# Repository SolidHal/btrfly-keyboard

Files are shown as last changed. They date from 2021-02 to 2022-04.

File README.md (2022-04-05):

# btrfly

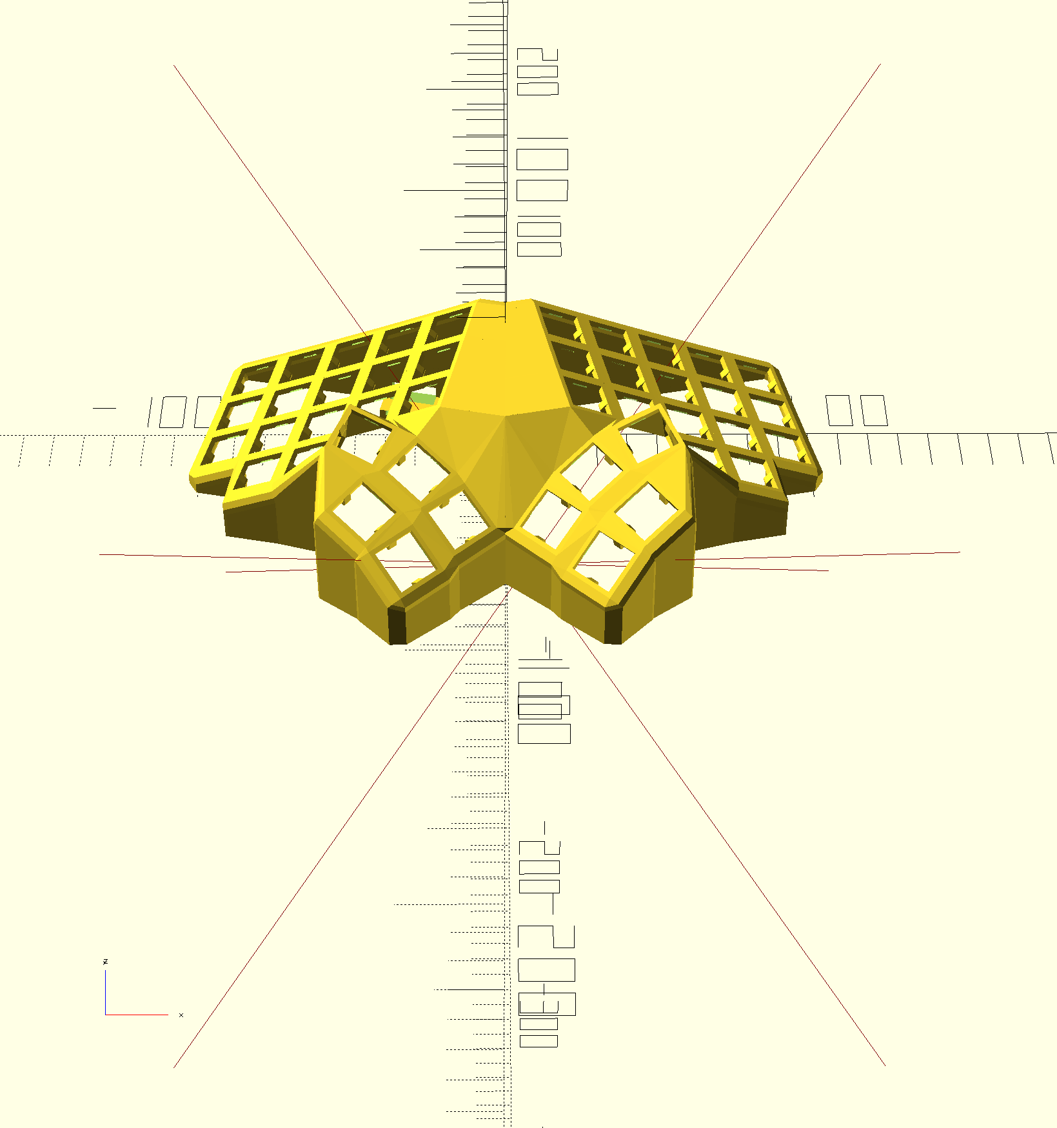
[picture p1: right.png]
render


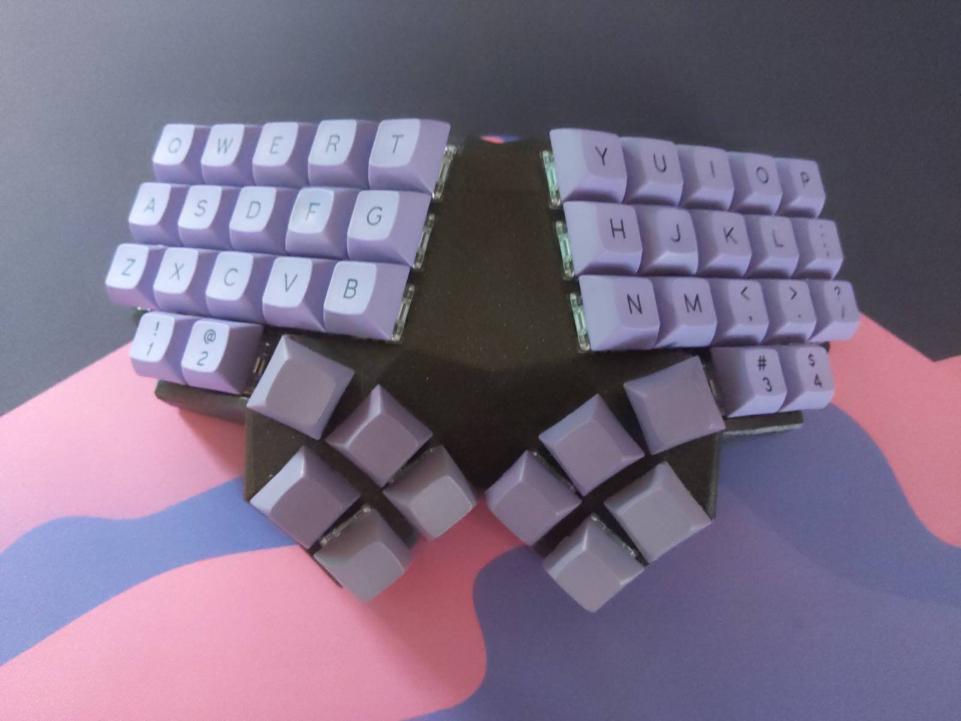
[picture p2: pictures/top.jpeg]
assembled


more pictures in `pictures`

This is a fork of the [Dactyl-ManuForm](https://github.com/tshort/dactyl-keyboard). The Dactyl-Manuform is a fork of the [Dactyl](https://github.com/adereth/dactyl-keyboard) with the thumb cluster from [ManuForm](https://github.com/jeffgran/ManuForm).

## Wiring

No "pretty" diagram for now, but there is an ugly hand drawn schematic. see `wiring.jpeg`

The schematic is from the perspective of the underside of the keyboard. 

Most of the "usual" dactyl wiring rules apply here.

ProMicro Pinout
```
C = colomn
R = Row

C0 = D3  USB   RAW
C1 = D2        GND
     GND       RST
     GND       VCC
C2 = D1        F4
C3 = D0        F5
C4 = D4        F6
C5 = C6        F7 = R0
C6 = D7        B1 = R1
C7 = E6        B3 = R2
C8 = B4        B2 = R3
C9 = B5        B6 = R4
```

## Build QMK
copy qmk/microdactyl to a new qmk checkout, under the keybaords/handwired directory
```
cp -a qmk/btrfly $QMK_DIR/keyboards/handwired/
```
then flash by running the following from your qmk checkout
```
make handwired/btrfly:default:flash
```

## Features

- dactyl-manuform-mini thumb cluster
- flat, tented qwerty keys
- 4 extra mappable keys

## Generate OpenSCAD and STL models

* Run `lein generate` or `lein auto generate`
* This will regenerate the `things/*.scad` files
* Use OpenSCAD to open a `.scad` file.
* Make changes to design, repeat `load-file`, OpenSCAD will watch for changes and rerender.
* When done, use OpenSCAD to export STL files

* NOTE: in the code, the btrfly keyboard is sometimes called "squish"

## In the wild
https://old.reddit.com/r/ErgoMechKeyboards/comments/nozw1c/btrfly_with_kissboard_configuration_my_first_diy/

## License

Copyright © 2021 Hal Emmerich
Copyright © 2015-2018 Matthew Adereth, Tom Short and Leo Lou

The source code for generating the models is distributed under the [GNU AFFERO GENERAL PUBLIC LICENSE Version 3](LICENSE).

The generated models are distributed under the [Creative Commons Attribution-ShareAlike 4.0 International (CC BY-SA 4.0)](LICENSE-models).

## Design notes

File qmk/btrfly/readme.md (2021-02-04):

# Microdactyl

to flash this keymap, grab a copy of qmk, copy this "microdactyl" directory into qmk/keyboards/handwired and from the qmk root run:
```
make handwired/microdactyl/4x6:default:flash
```

you can also get a .json file to upload to the qmk configurator by running:
```
./bin/qmk c2json -km DEFAULT -kb handwired/microdactyl/4x6 'keyboards/handwired/microdactyl/4x6/keymaps/default/keymap.c' > microdactyl.json 
```

to get the configurator to recognize the file you might have to change the keyboard name to `handwired/dactyl-manuform/4x6`

Dactyl Manuform (4x5, 5x6, 5x7, 6x6)
======
the [Dactyl-Manuform](https://github.com/tshort/dactyl-keyboard) is a split curved keyboard based on the design of [adereth dactyl](https://github.com/adereth/dactyl-keyboard) and thumb cluster design of the [manuform](https://geekhack.org/index.php?topic=46015.0) keyboard, the hardware is similar to the let's split keyboard. all information needed for making one is in the first link.
Imgur

## First Time Setup

Download or clone the `qmk_firmware` repo and navigate to its top level directory. Once your build environment is setup, you'll be able to generate the default .hex using:

Depending on your Layout chose one of the follwing commands:

```
$ make handwired/dactyl_manuform/YOUR_LAYOUT:YOUR_KEYMAP_NAME
```

example:
```
$ make handwired/dactyl_manuform/4x5:default
```

If everything worked correctly you will see a file:

```
dactyl_manuform_YOUR_LAYOUT_YOUR_KEYMAP_NAME.hex
```

For more information on customizing keymaps, take a look at the primary documentation for [Customizing Your Keymap](/docs/faq_keymap.md) in the main readme.md.

## Keymaps

### [Keymaps 4x5](/keyboards/handwired/dactyl_manuform/4x5/keymaps/)

#### Default
Simple QWERTY layout with 3 Layers.
#### Dvorak

### [Keymaps 5x6](/keyboards/handwired/dactyl_manuform/5x6/keymaps/)

#### Default
Just a copy of the Impstyle keymap. Feel free to adjust it.

#### Impstyle
A simple QWERTY keymap with 3 Layers. Both sides are connected via serial and the Left ist the master.

### [Keymaps 5x7 aka almost Ergodox](/keyboards/handwired/dactyl_manuform/5x7/keymaps/)
#### Default
Keymap of Loligagger from geekhack.

### [Keymaps 6x6](/keyboards/handwired/dactyl_manuform/6x6/keymaps/)

#### Default
Simple QWERTY layout with 3 Layers.

## Required Hardware

Apart from diodes and key switches for the keyboard matrix in each half, you
will need:

* 2 Arduino Pro Micros. You can find these on AliExpress for ≈3.50USD each.
* 2 TRRS sockets and 1 TRRS cable, or 2 TRS sockets and 1 TRS cable

Alternatively, you can use any sort of cable and socket that has at least 3
wires. If you want to use I2C to communicate between halves, you will need a
cable with at least 4 wires and 2x 4.7kΩ pull-up resistors

## Optional Hardware
A speaker can be hooked-up to either side to the `5` (`C6`) pin and `GND`, and turned on via `AUDIO_ENABLE`.

## Wiring

The 3 wires of the TRS/TRRS cable need to connect GND, VCC, and digital pin 3 (i.e.
PD0 on the ATmega32u4) between the two Pro Micros.

Next, wire your key matrix to any of the remaining 17 IO pins of the pro micro
and modify the `matrix.c` accordingly.

The wiring for serial:

serial wiring

The wiring for i2c:

i2c wiring

The pull-up resistors may be placed on either half. It is also possible
to use 4 resistors and have the pull-ups in both halves, but this is
unnecessary in simple use cases.

You can change your configuration between serial and i2c by modifying your `config.h` file.

## Notes on Software Configuration

the keymaps in here are for the 4x5 layout of the keyboard only.

## Flashing

To flash your firmware take a look at: [Flashing Instructions and Bootloader Information](https://docs.qmk.fm/#/flashing)

## Choosing which board to plug the USB cable into (choosing Master)

Because the two boards are identical, the firmware has logic to differentiate the left and right board.

It uses two strategies to figure things out: looking at the EEPROM (memory on the chip) or looking if the current board has the usb cable.

The EEPROM approach requires additional setup (flashing the eeprom) but allows you to swap the usb cable to either side.

The USB cable approach is easier to setup and if you just want the usb cable on the left board, you do not need to do anything extra.

### Setting the left hand as master

If you always plug the usb cable into the left board, nothing extra is needed as this is the default. Comment out `EE_HANDS` and comment out `I2C_MASTER_RIGHT` or `MASTER_RIGHT` if for some reason it was set.

### Setting the right hand as master

If you always plug the usb cable into the right board, add an extra flag to your `config.h`
```
 #define MASTER_RIGHT
```

### Setting EE_hands to use either hands as master

If you define `EE_HANDS` in your `config.h`, you will need to set the
EEPROM for the left and right halves.

The EEPROM is used to store whether the
half is left handed or right handed. This makes it so that the same firmware
file will run on both hands instead of having to flash left and right handed
versions of the firmware to each half. To flash the EEPROM file for the left
half run:
```
make handwired/dactyl_promicro:default:dfu-split-left
make handwired/dactyl_promicro:default:dfu-split-right
```

After you have flashed the EEPROM, you then need to set `EE_HANDS` in your config.h, rebuild the hex files and reflash.

Note that you need to program both halves, but you have the option of using
different keymaps for each half. You could program the left half with a QWERTY
layout and the right half with a Colemak layout using bootmagic's default layout option.
Then if you connect the left half to a computer by USB the keyboard will use QWERTY and Colemak when the
right half is connected.

Notes on Using Pro Micro 3.3V
-----------------------------

Do update the `F_CPU` parameter in `rules.mk` to `8000000` which reflects
the frequency on the 3.3V board.

Also, if the slave board is producing weird characters in certain columns,
update the following line in `matrix.c` to the following:

```
// wait_us(30);  // without this wait read unstable value.
wait_us(300);  // without this wait read unstable value.
```

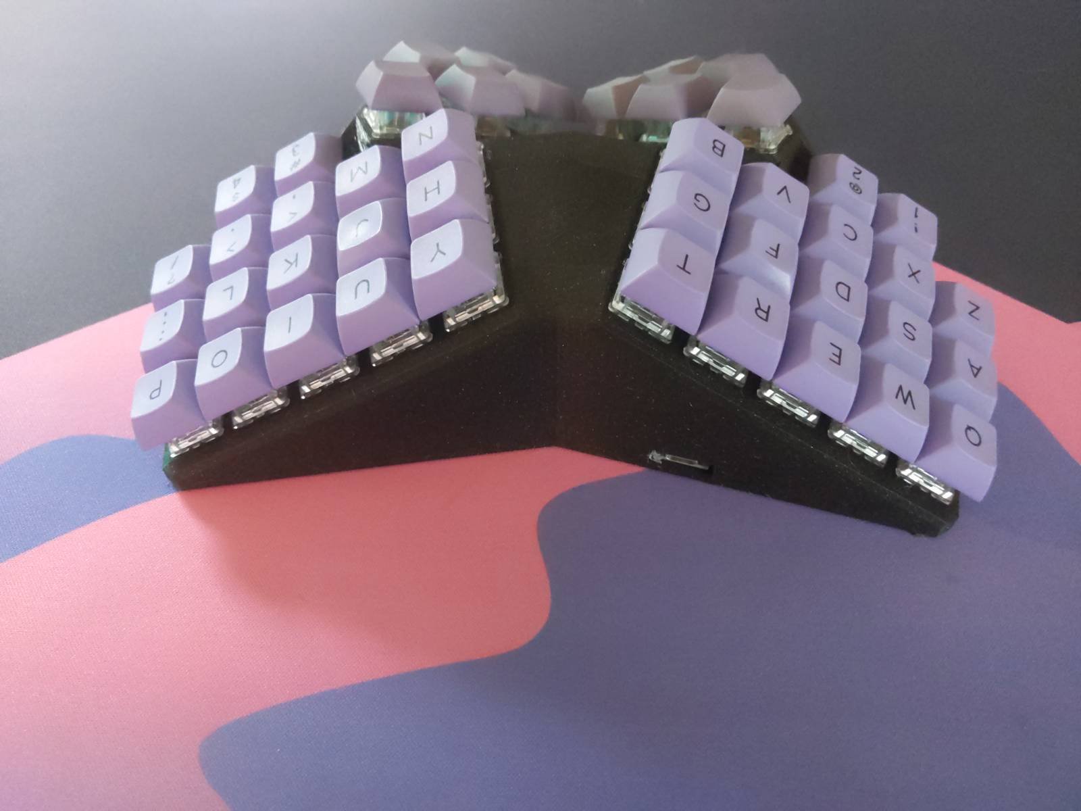
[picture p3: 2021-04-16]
pictures/back.jpeg

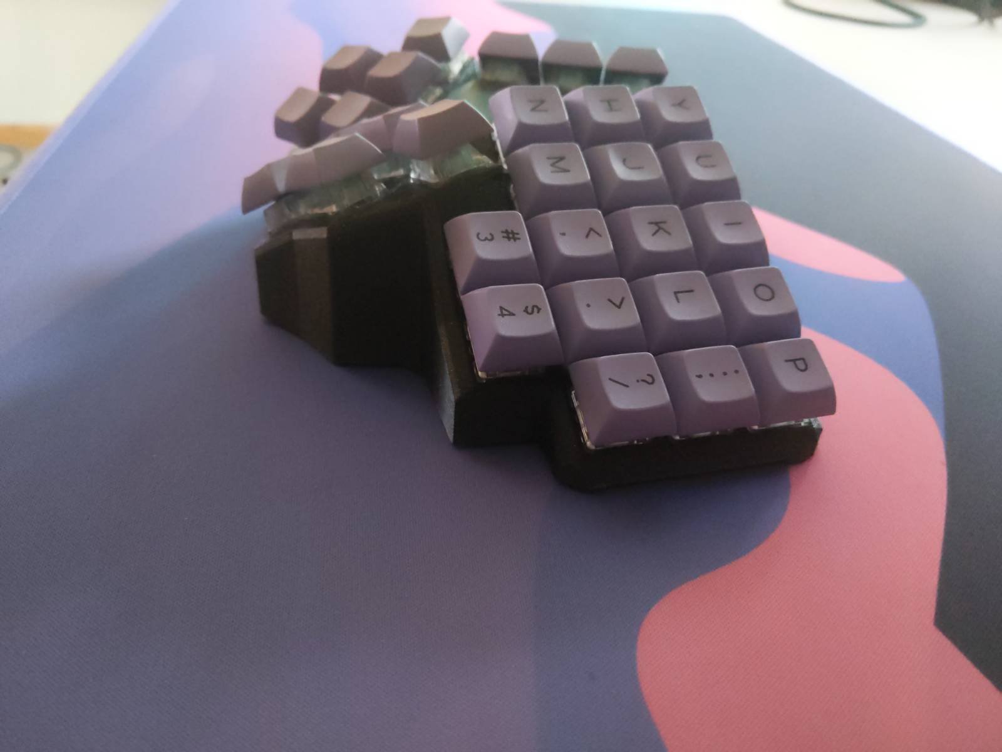
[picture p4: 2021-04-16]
pictures/right_side.jpeg

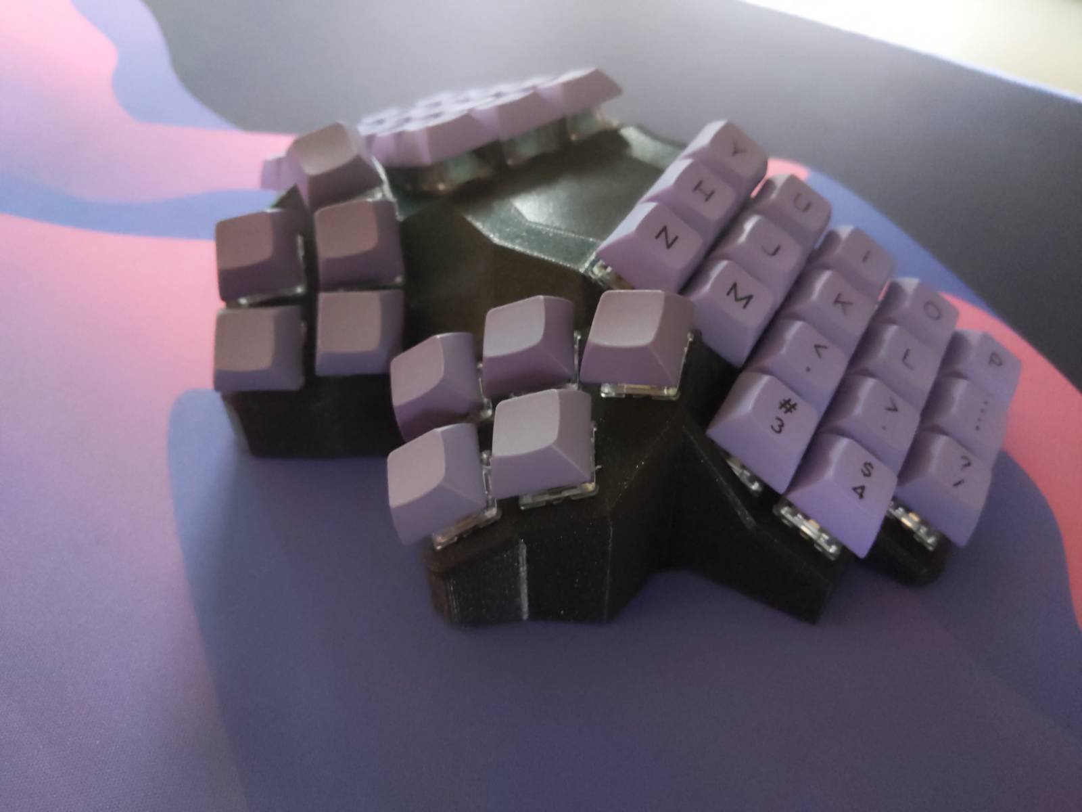
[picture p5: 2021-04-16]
pictures/front_right.jpeg

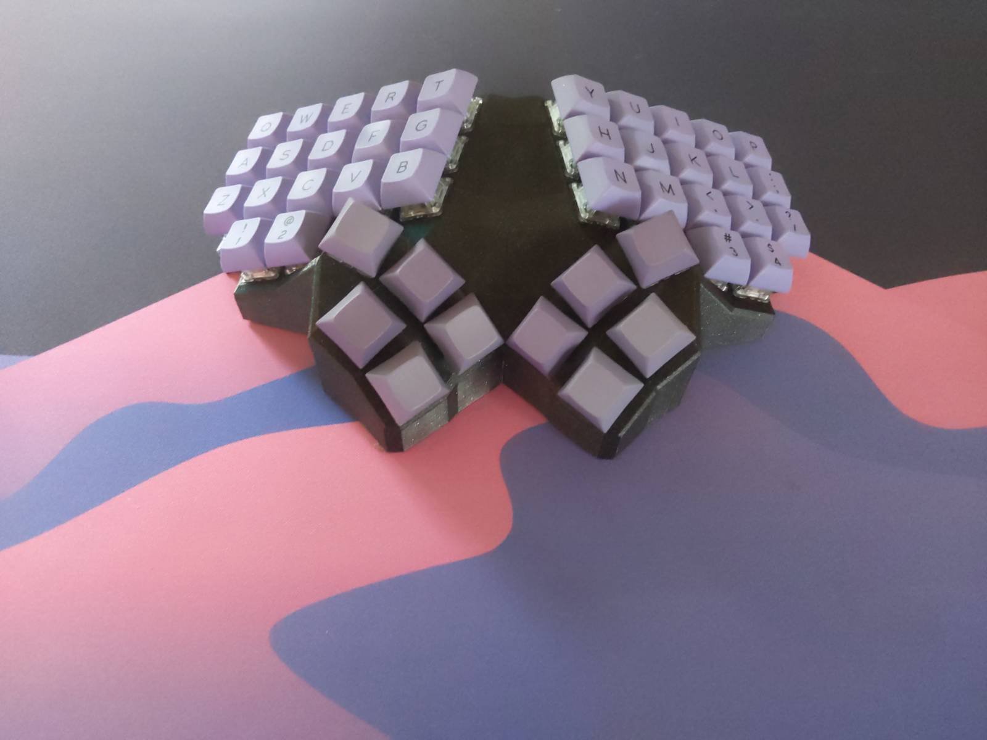
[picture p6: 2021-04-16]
pictures/front.jpeg

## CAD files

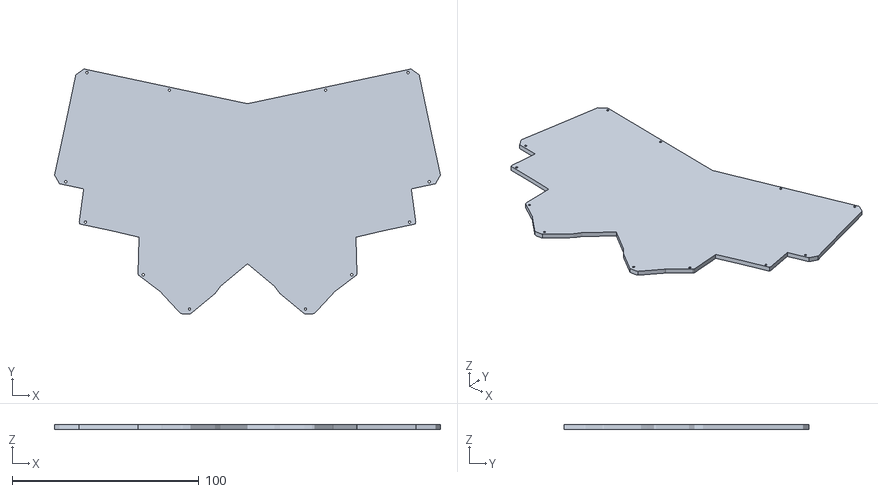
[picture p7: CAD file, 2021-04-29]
things/squish-plate.stl
206.9 x 131.3 x 2.50

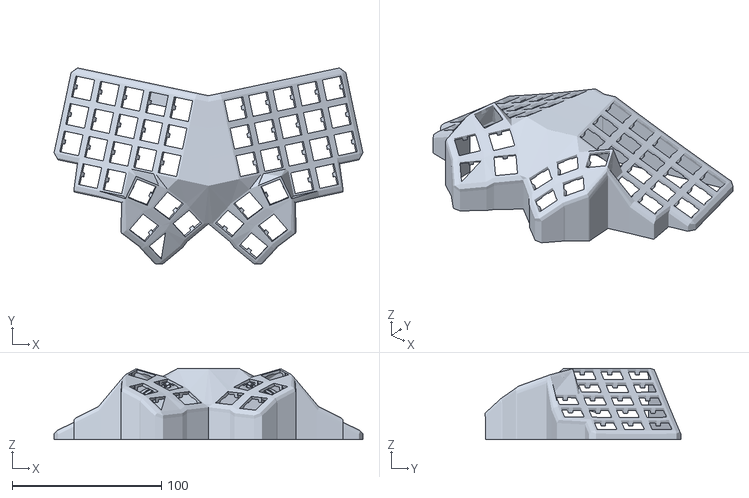
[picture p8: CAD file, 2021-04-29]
things/squish.stl
206.9 x 131.3 x 47.8

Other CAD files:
things/left.scad
things/right-plate.scad
things/right.scad
things/right-test.scad
things/test.scad

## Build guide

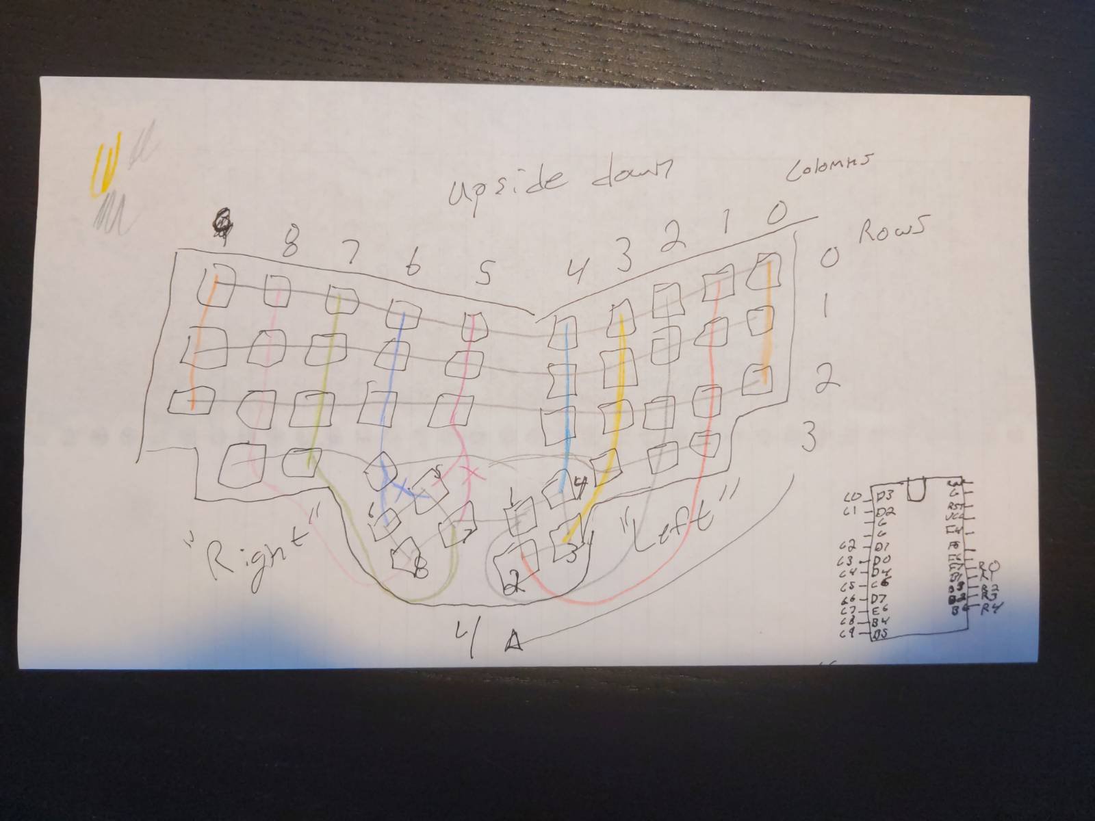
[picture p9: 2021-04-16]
wiring.jpeg

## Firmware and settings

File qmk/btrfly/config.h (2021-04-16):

/*
Copyright 2012 Jun Wako <wakojun@gmail.com>
Copyright 2015 Jack Humbert

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
You should have received a copy of the GNU General Public License
along with this program.  If not, see <http://www.gnu.org/licenses/>.
*/

#pragma once

#include "config_common.h"

/* USB Device descriptor parameter */
#define VENDOR_ID       0x444D
#define MANUFACTURER    tshort
#define PRODUCT_ID      0x3436
#define DEVICE_VER      0x0001

/* mouse config */
#define MOUSEKEY_INTERVAL       20
#define MOUSEKEY_DELAY          0
#define MOUSEKEY_TIME_TO_MAX    60
#define MOUSEKEY_MAX_SPEED      7
#define MOUSEKEY_WHEEL_DELAY 0

/* Set 0 if debouncing isn't needed */
#define DEBOUNCE 5

/* serial.c configuration for split keyboard */
#define SOFT_SERIAL_PIN D0

/* Mechanical locking support. Use KC_LCAP, KC_LNUM or KC_LSCR instead in keymap */
#define LOCKING_SUPPORT_ENABLE
/* Locking resynchronize hack */
#define LOCKING_RESYNC_ENABLE

/* Enables This makes it easier for fast typists to use dual-function keys */
#define PERMISSIVE_HOLD

/* key matrix size */
#define MATRIX_ROWS 5
#define MATRIX_COLS 10

// row-driven
#define MATRIX_ROW_PINS { F7, B1, B3, B2, B6 }
#define MATRIX_COL_PINS { D3, D2, D1, D0, D4, C6, D7, E6, B4, B5 }

/* COL2ROW or ROW2COL */
#define DIODE_DIRECTION COL2ROW

/*
 * Feature disable options
 *  These options are also useful to firmware size reduction.
 */

/* disable debug print */
// #define NO_DEBUG

/* disable print */
// #define NO_PRINT

/* disable action features */
//#define NO_ACTION_LAYER
//#define NO_ACTION_TAPPING
//#define NO_ACTION_ONESHOT
//#define NO_ACTION_MACRO
//#define NO_ACTION_FUNCTION

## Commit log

2020-12-24 create 4x6 things
    [left.scad, right-plate.scad, right-test.scad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]
2020-12-24 made pinkies 1u, no one wants to have to find 1.5u keys. Fixed plate holes to accomedate
    [left.scad, right-plate.scad, right-test.scad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]
2021-01-11 correct gitignore
    [left.stl, right.stl]
2021-01-29 fixup pinkies
    [left.scad, left.stl, right-plate.scad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]
2021-01-30 move pinkes down in height a bit more
    [left.scad, left.stl, right-plate.scad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]
2021-02-08 increase angle, make usb port hole larger
    adjust microcontroller holder and screw hole nubs
    [left.scad, left.stl, right-plate.scad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]
2021-02-09 move thumb cluster closer together
    since I am using DSA, I don't need the extra space
    [left.scad, right-plate.scad, right-test.scad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]
2021-02-09 remove 2nd pinky colomn
    [left.scad, left.stl, right-plate.scad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]
2021-02-11 increase tenting
    [left.scad, left.stl, right-plate.scad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]
2021-04-01 flattened, combined halves, need to work on walls
    [left.scad, right-plate.scad, right-test.scad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]
2021-04-01 closed up the ceiling and front
    [left.scad, right-plate.scad, right-test.scad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]
2021-04-02 get most of thumb squish closed
    [left.scad, right-plate.scad, right-test.scad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]
2021-04-02 closed up thumb gap
    [left.scad, right-plate.scad, right-test.scad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]
2021-04-02 removed screw holes, rev 1 complete
    [right.scad]
2021-04-05 generate stl
    [left.stl, right.stl, squish.stl]
2021-04-05 fix key spacing
    [left.scad, right-plate.scad, right-test.scad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]
2021-04-05 fix bad volume, remove holder for now
    [left.scad, right-plate.scad, right-test.scad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]
2021-04-06 increase spacing between rows
    [left.scad, right-plate.scad, right-test.scad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]
2021-04-29 added printable bottom plate, and holes
    [left.scad, right-plate.scad, right-test.scad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]

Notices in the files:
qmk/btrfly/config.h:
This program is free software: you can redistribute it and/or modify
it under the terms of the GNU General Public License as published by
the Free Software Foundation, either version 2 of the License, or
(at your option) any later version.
